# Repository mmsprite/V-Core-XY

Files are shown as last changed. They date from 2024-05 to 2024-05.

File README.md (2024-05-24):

# V-Core-XY
An Open Source upgrade of the Tronxy X5SA Pro to a highly capable 3D Printer based on Klipper and the Voron Teams Designs

**CAUTION: THIS PRINTER IS NOT BEGINNER FRIENDLY TO BUILD, MAKE SURE YOU HAVE EXPERIENCE OR HAVE SOMEONE EXPERIENCED WITH YOU**

Step 1: Choosing your Parts
https://docs.google.com/spreadsheets/d/1tDaB7JIVnb1R4yDRam50uJWcxuR9Q7Ubok1-GsZLodY/edit?usp=sharing

**Required Options:**

**Boards:**
SKR 3 or SKR Mini E3 V3

**Toolhead:**
Voron Stealthburner

**Hotends:**
Any Voron Stealthburner compatible,
recommended: Phaetus Dragon HF

**Extruders:**
Clockwork 2 or Galileo 2 (recommended)

**Optionals:** 
Enclosure,
Klipperscreen Touchscreen,
Camera,
Voron Stealthburner with BTT Knomi,
LED Printarea Lights

**INSTRUCTIONS**
Step 0:
Purchase all required Parts of the BOM and a Tronxy X5SA-Pro(buying a used one is recommended)

Step 1:
3D Print all required Parts and chosen Optional Parts, recommended is PETG or PLA+
Custom Parts of the V-CORE-XY Project are marked with an [a] for to indicate Accent Parts to be printed in a chosen Accent color if desired
the quantity of needed Parts is marked with a (qX)

Step 2:
assemble the Parts as directed by their individual Instructions and Mount them to the Printer

Step 3: Wiring
Wiring can be confusing, i recommend using the Pinouts of the SKR Boards to help, it may require Trial and Error to get the Wiring right

Step 4: Flashing https://docs.mainsail.xyz/
Install Mainsail on the Raspberry Pi and flash the SKR with the Klipper firmware 

Step 5: Done
Enjoy your new Printer with all its upgrades
If needed you can add a Touchscreen and Lights as directed, the Printer is also compatible with any Klipper compatible Project like Enraged Rabbit for Multimaterial Printing

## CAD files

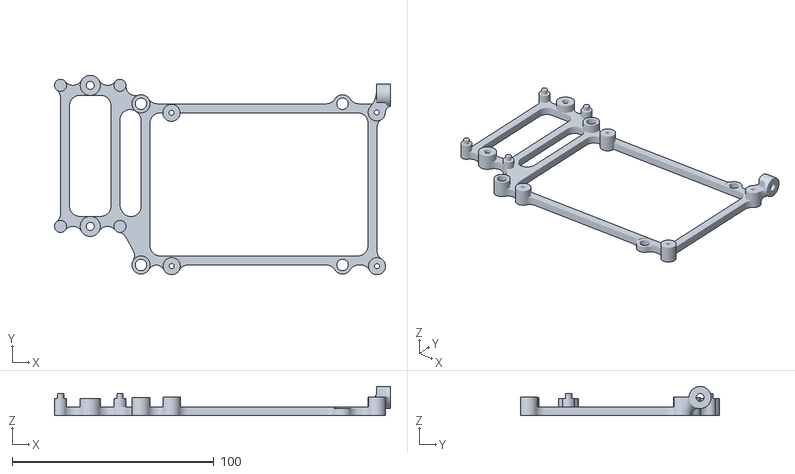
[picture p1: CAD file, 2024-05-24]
Required Printed Parts/SKR 3 Adapter (q1).stl
166.7 x 99.0 x 14.5

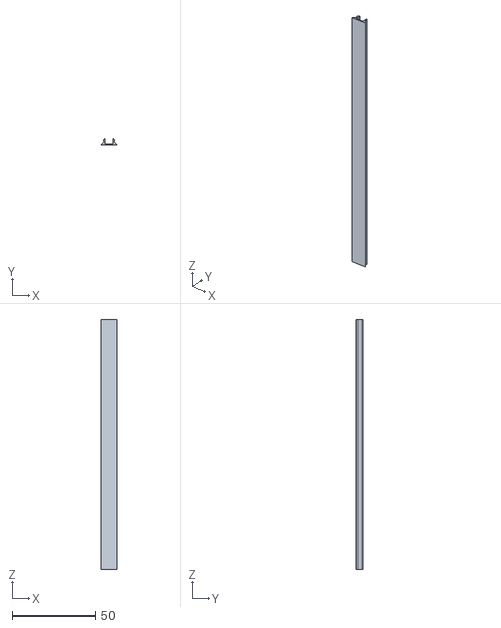
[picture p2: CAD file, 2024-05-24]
Required Printed Parts/vslot cover.stl
9.40 x 4.00 x 150.0

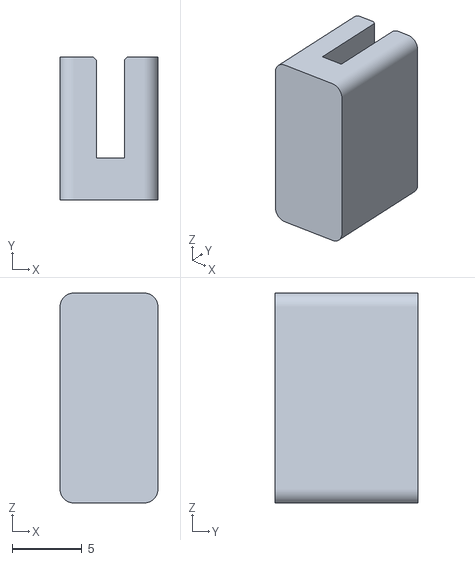
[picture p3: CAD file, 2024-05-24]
Required Printed Parts/GT2 BELT CLAMP (q4).stl
7.00 x 10.2 x 15.0

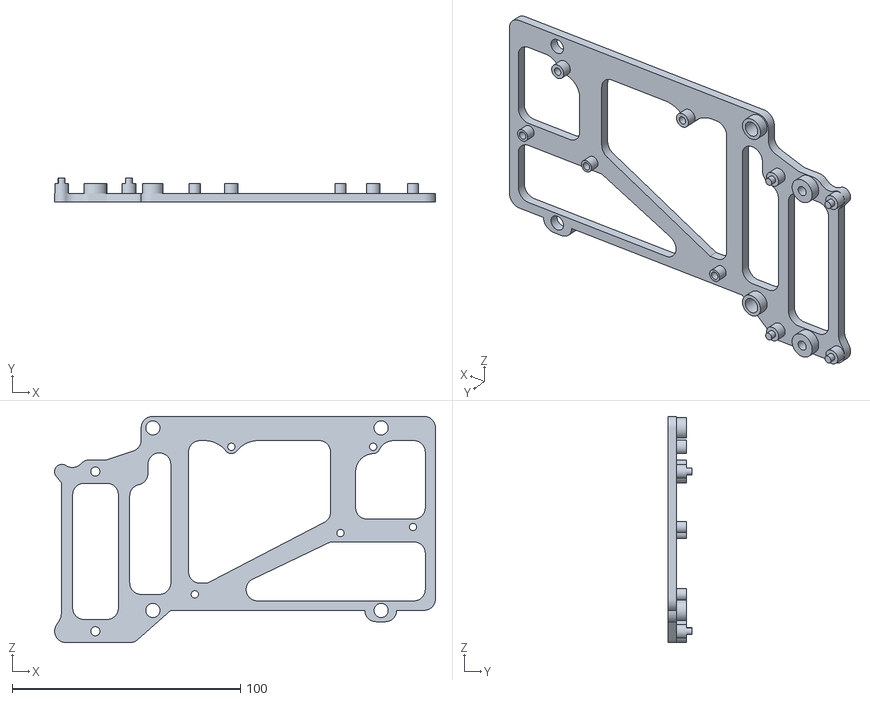
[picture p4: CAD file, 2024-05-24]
Required Printed Parts/SKR MINI E3 V3 Adapter.stl
167.0 x 10.5 x 99.1

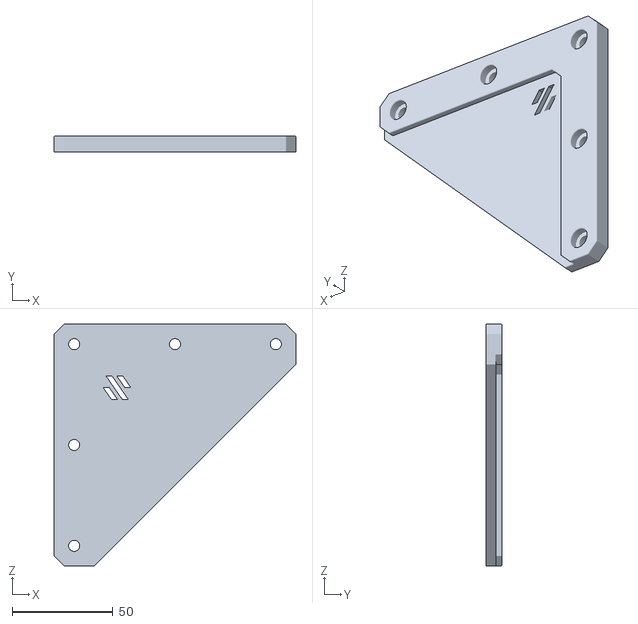
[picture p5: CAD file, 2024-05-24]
Required Printed Parts/CornerBrace(q8).stl
120.0 x 8.00 x 120.0

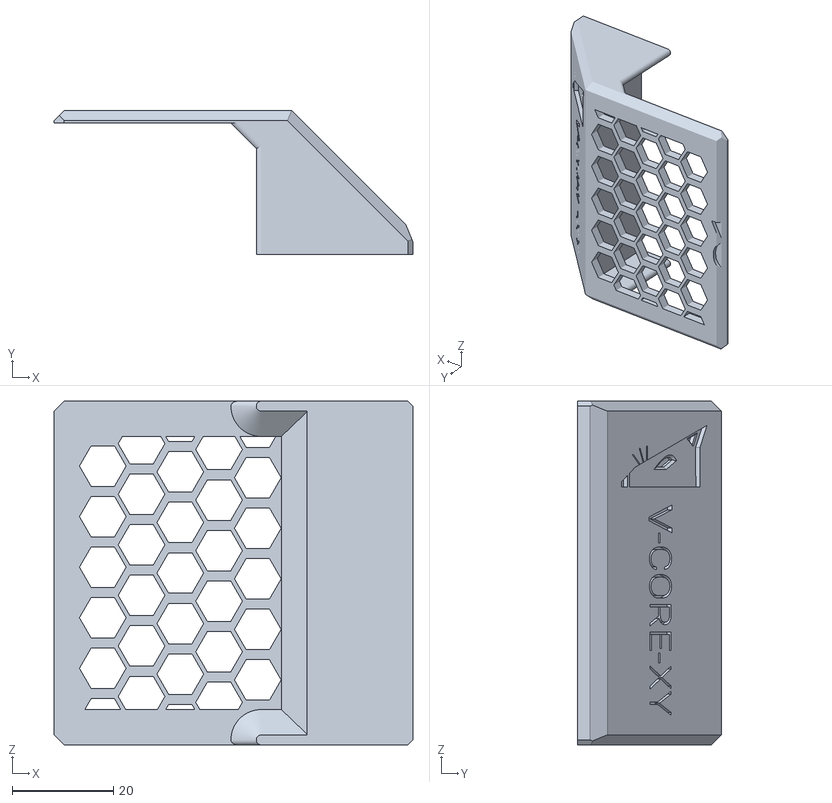
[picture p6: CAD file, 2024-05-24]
Required Printed Parts/Belt Axis Cover (q2).stl
71.0 x 28.5 x 68.0

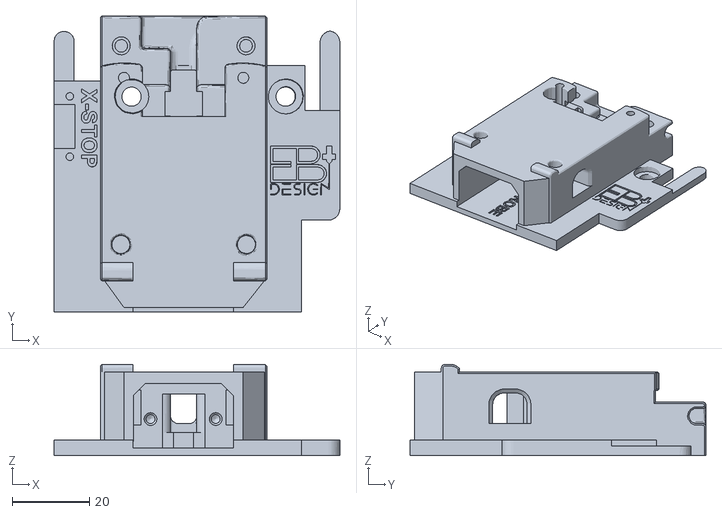
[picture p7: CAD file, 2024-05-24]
Required Printed Parts/Stealthburner Adapter (q1) PETG.stl
74.2 x 76.9 x 23.7

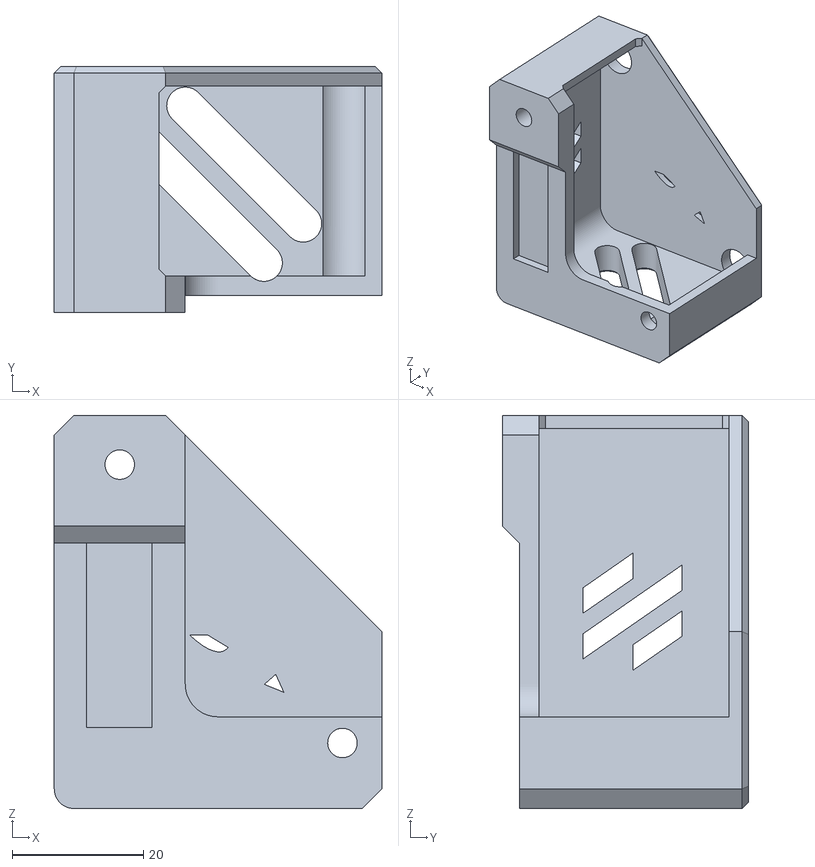
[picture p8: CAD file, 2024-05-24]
Required Printed Parts/Ratrig X Voron Corner Belt Cover [a] (q2).stl
50.0 x 37.6 x 60.0

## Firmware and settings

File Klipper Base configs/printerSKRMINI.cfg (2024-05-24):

[include mainsail.cfg]
[include KAMP_Settings.cfg]
[exclude_object]
[include macros.cfg]
#[include PIS.cfg]
[include led_progress.cfg]

[virtual_sdcard]
path: /home/pi/printer_data/gcodes
on_error_gcode: CANCEL_PRINT

[mcu]
serial: /dev/serial/by-id/usb-Klipper_stm32g0b1xx_1B002C001250415833323520-if00
restart_method: command

[neopixel my_neopixel]
pin: PA8
chain_count: 148
initial_RED: 0.4
initial_GREEN: 0.4
initial_BLUE: 0.4

[gcode_macro POWER_OFF_PRINTER]
gcode:
  {action_call_remote_method(
    "set_device_power", device="V-Core", state="off"
  )}
  
[delayed_gcode delayed_printer_off]
initial_duration: 0.
gcode:
  {% if printer.idle_timeout.state == "Idle" %}
    POWER_OFF_PRINTER
  {% endif %}

[idle_timeout]
gcode:
  M84
  TURN_OFF_HEATERS
  UPDATE_DELAYED_GCODE ID=delayed_printer_off DURATION=6


[printer]
kinematics: corexy
max_velocity: 500
max_accel: 15000
max_z_velocity: 20
max_z_accel: 100

[safe_z_home]
home_xy_position: 165,142 # Change coordinates to the center of your print bed
speed: 120
z_hop: 5                 # Move up 10mm
z_hop_speed: 10

[bed_mesh]
speed: 140
horizontal_move_z: 2.5
mesh_min: 10, 22
mesh_max: 315, 305
probe_count: 6,6

[gcode_macro PROBE_DOWN]
gcode:
    SET_PIN PIN=probe_enable VALUE=1

[gcode_macro PROBE_UP]
gcode:
    SET_PIN PIN=probe_enable VALUE=0

[output_pin probe_enable]
pin: PA1  # Set to the control pin on your board
value: 0

[probe]
pin: ^!PC14  # NOTE FOR V2 users: Set this to ^!PC14 to set the low level trigger 
deactivate_on_each_sample: False
speed: 2.5
x_offset: 0
y_offset: 20
z_offset: 0.76
samples: 1
samples_tolerance: 0.02
samples_tolerance_retries: 3
activate_gcode:
    PROBE_DOWN
    G4 P500
deactivate_gcode:
    PROBE_UP

[stepper_x]
step_pin: PB13
dir_pin: !PB12
enable_pin: !PB14
microsteps: 64
rotation_distance: 40
endstop_pin: !PC0
position_endstop: 0
position_max: 336
homing_speed: 100

[tmc2209 stepper_x]
uart_pin: PC11
tx_pin: PC10
uart_address: 0
run_current: 1.4
stealthchop_threshold: 999999

[stepper_y]
step_pin: PB10
dir_pin: !PB2
enable_pin: !PB11
microsteps: 64
rotation_distance: 40
endstop_pin: !PC1
position_endstop: 0
position_max: 305
homing_speed: 100

[tmc2209 stepper_y]
uart_pin: PC11
tx_pin: PC10
uart_address: 2
run_current: 1.4
stealthchop_threshold: 999999

[stepper_z]
step_pin: PB0
dir_pin: !PC5
enable_pin: !PB1
microsteps: 16
rotation_distance: 8
endstop_pin: probe:z_virtual_endstop
position_max: 380
position_min: -2

[tmc2209 stepper_z]
uart_pin: PC11
tx_pin: PC10
uart_address: 1
run_current: 0.580
hold_current: 0.500
stealthchop_threshold: 999999

[extruder]
step_pin: !PB3
dir_pin: !PB4
enable_pin: !PD1
rotation_distance: 47.088
gear_ratio: 9:1
microsteps: 16
nozzle_diameter: 0.400
filament_diameter: 1.750
heater_pin: PC8
sensor_type: EPCOS 100K B57560G104F
sensor_pin: PA0
#control: pid
#pid_Kp: 21.527
#pid_Ki: 1.063
#pid_Kd: 108.982
min_temp: 0
max_temp: 350
max_extrude_only_distance: 350
max_extrude_cross_section: 5
min_extrude_temp: 20
pressure_advance: 0

[tmc2209 extruder]
uart_pin: PC11
tx_pin: PC10
uart_address: 3
run_current: 0.7
stealthchop_threshold: 0

[firmware_retraction]
retract_length: 2.5
retract_speed: 24
unretract_extra_length: 0
unretract_speed: 30



[heater_bed]
heater_pin: PC9
sensor_type: ATC Semitec 104GT-2
sensor_pin: PC4
#control: pid
#pid_Kp: 54.027
#pid_Ki: 0.770
#pid_Kd: 948.182
min_temp: 0
max_temp: 130

[heater_fan heatbreak_cooling_fan]
pin: PC6

[controller_fan controller_fan]
pin: PC7
stepper: stepper_x

[fan]
pin: PB15

[fan_generic enclosure_fan]
pin: PB5




[screws_tilt_adjust]
screw1:5,275
screw2:320,275
screw3:5,0
screw4:320,0
speed: 150
horizontal_move_z: 5

#[board_pins]
#aliases:
    # EXP1 header
    #EXP1_1=PB5,  EXP1_3=PA9,   EXP1_5=PA10, EXP1_7=PB8, EXP1_9=<GND>,
    #EXP1_2=PA15, EXP1_4=<RST>, EXP1_6=PB9,  EXP1_8=PD6, EXP1_10=<5V>

#*# <---------------------- SAVE_CONFIG ---------------------->
#*# DO NOT EDIT THIS BLOCK OR BELOW. The contents are auto-generated.
#*#
#*# [extruder]
#*# control = pid
#*# pid_kp = 20.230
#*# pid_ki = 0.905
#*# pid_kd = 113.036
#*#
#*# [heater_bed]
#*# control = pid
#*# pid_kp = 70.866
#*# pid_ki = 1.109
#*# pid_kd = 1132.082
#*#
#*# [input_shaper]
#*# shaper_type_x = mzv
#*# shaper_freq_x = 67.8
#*# shaper_type_y = ei
#*# shaper_freq_y = 61.8

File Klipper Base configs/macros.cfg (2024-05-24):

#### MACROS

[gcode_macro NOZZLE_WIPE]
gcode:
    G90
    G1 Z10 F3000
    G1 X335 Y45 Z3.2 F3000
    G1 X335 Y25 F10000 #1
    G1 X335 Y45 F10000
    G1 X335 Y25 F10000 #2
    G1 X335 Y45 F10000
    G1 X335 Y25 F10000 #3
    G1 X335 Y45 F10000
    G1 X335 Y25 F10000 #4
    G1 X335 Y45 F10000
    G1 X335 Y25 F10000 #5
    G1 X335 Y45 F10000
    G1 X335 Y25 F10000 #6
    G1 X335 Y45 F10000
    G1 X335 Y25 F10000 #7
    G1 X335 Y45 F10000
    G1 X335 Y25 F10000 #8
    G1 X335 Y45 F10000
    G1 X335 Y25 F10000 #9
    G1 X335 Y45 F10000
    G1 X335 Y25 F10000 #10
    G1 Z10 F3000
    G1 X165 Y165 F3000
   
    

[gcode_macro START_PRINT]
gcode:
    {% set BED_TEMP = params.BED_TEMP|default(65)|float %}
    {% set EXTRUDER_TEMP = params.EXTRUDER_TEMP|default(215)|float %}
    G28
    G90
    G1 X0 Y305 Z15 F4000
    NEOPIXEL_DISPLAY LED=my_neopixel TYPE=bed_temp MODE=glow
    M190 S{BED_TEMP}
    BED_MESH_CALIBRATE
    G90
    SMART_PARK
    NEOPIXEL_DISPLAY LED=my_neopixel TYPE=extruder_temp MODE=glow
    M109 S{EXTRUDER_TEMP}
    VORON_PURGE
    NEOPIXEL_DISPLAY LED=my_neopixel TYPE=print_percent MODE=glow

[gcode_macro END_PRINT]
gcode:
    # Turn off bed, extruder, and fan
    M140 S0
    M104 S0
    M106 S0
    # Move nozzle away from print while retracting
    G91
    G1 E-5 F2700 ;Retract a bit
    # Raise nozzle by 10mm
    # Move Bed all the way down and Move Toolhead to Home
    G91
    G1 Z20 F3000
    G90 
    G1 X20 Y305  F5000
    M84
    SET_LED LED=my_neopixel RED=0 GREEN=0.3 BLUE=0.3 INDEX=145



[gcode_macro PAUSE]
description: Pause the actual running print
rename_existing: PAUSE_BASE
gcode:
  PAUSE_BASE
  _TOOLHEAD_PARK_PAUSE_CANCEL

#M205 is added by Cura and not supported by Klipper
[gcode_macro M205]
gcode: M117 Printing...

[gcode_macro M600]
gcode:
  {% set X = params.X|default(50)|float %}
  {% set Y = params.Y|default(0)|float %}
  {% set Z = params.Z|default(10)|float %}
  SAVE_GCODE_STATE NAME=M600_state
  PAUSE
  G91
    G1 E-3 F2700 ;Retract a bit
    # Raise nozzle by 10mm
    # Move Bed all the way down and Move Toolhead to Home
    G91
    G1 Z20 F3000
    G90 
    G1 X0 Y305  F3000
  G91
  #G1 E-150 F500 retract
  RESTORE_GCODE_STATE NAME=M600_state
  #SET_IDLE_TIMEOUT TIMEOUT=43000

[gcode_macro G29]
gcode: 
  G28
  BED_MESH_CALIBRATE
  BED_MESH_PROFILE SAVE=probed
  BED_MESH_PROFILE LOAD=probed

[gcode_macro CANCEL_PRINT]
description: Cancel the actual running print
rename_existing: CANCEL_PRINT_BASE
gcode:
  # Turn off bed, extruder, and fan
    M140 S0
    M104 S0
    M106 S0
    # Move nozzle away from print while retracting
    G91
    G1 E-3 F2700 ;Retract a bit
    # Raise nozzle by 10mm
    # Move Bed all the way down and Move Toolhead to Home
    G91
    G1 Z20 F3000
    G90 
    G1 X0 Y305  F3000
    M84
  CLEAR_PAUSE
  SDCARD_RESET_FILE

[gcode_macro M600]
description: Starts process of Filament Change
gcode:
  {% if printer.extruder.temperature < 180 %}
    {action_respond_info("Extruder temperature too low")}
  {% else %}
    PAUSE_MACRO
    _DISABLE_FS
    UNLOAD_FILAMENT
  {% endif %}
 
[gcode_macro PAUSE_MACRO]
description: Pauses Print
gcode:
    PAUSE
    SET_IDLE_TIMEOUT TIMEOUT={ 30 * 60 }
 
[gcode_macro FC_RESUME]
description: Resume print after Filament Change
gcode:
    ##### read E from pause macro #####
    {% set E = printer["gcode_macro PAUSE"].extrude|float %}
    SET_IDLE_TIMEOUT TIMEOUT={ 10 * 60 }
    G1 E-{ E }
    # Reset extruder position
    G92 E0
    RESUME
 
[gcode_macro UNLOAD_FILAMENT]
description: Unloads Filament from extruder
gcode:
  {% if printer.extruder.temperature < 180 %}
    {action_respond_info("Extruder temperature too low")}
  {% else %}
    SAVE_GCODE_STATE NAME=UNLOAD_state
    {% set Z = params.Z|default(50)|int %}
    {% set axis_max = printer.toolhead.axis_maximum %}
    {% set pos = printer.toolhead.position %}
 
    {% set z_diff = axis_max.z - pos.z %}
    {% set z_safe_lift = [ Z, z_diff ] | min%}
 
    G91                   # relative positioning
    G0 Z{ z_safe_lift }
    # Reset extruder position
    G92 E0
    G1 E5.0 F300        # extrude a little
    G1 E-50 F{ 10 * 60 } # perform the unload
    G1 E-50 F{ 5 * 60 }   # finish the unload
    RESTORE_GCODE_STATE NAME=UNLOAD_state
  {% endif %}
 
[gcode_macro PURGE]
description: Extrudes filament, used to clean out previous filament
gcode:
  {% if printer.extruder.temperature < 180 %}
    {action_respond_info("Extruder temperature too low")}
  {% else %}
  {% set PURGE_AMOUNT = params.PURGE_AMOUNT|default(40)|float %}
    SAVE_GCODE_STATE NAME=PURGE_state
    G91                   # relative coords
    G1 E{PURGE_AMOUNT} F{ 5 * 60 }  # purge
    RESTORE_GCODE_STATE NAME=PURGE_state
  {% endif %}
 
[gcode_macro LOAD_FILAMENT]
description: Loads filament into the extruder
gcode:
  {% if printer.extruder.temperature < 180 %}
    {action_respond_info("Extruder temperature too low")}
  {% else %}
    SAVE_GCODE_STATE NAME=LOAD_state
    G91                   # Relative coords
    G1 E50 F{ 5 * 60 }  # extrude
    G4 P{ 0.9 * 1000 }    # dwell (ms)
    G1 E25.0 F{ 5 * 60 }  # extrude a little more
    _ENABLE_FS
    RESTORE_GCODE_STATE NAME=LOAD_state
  {% endif %}
 
[gcode_macro _DISABLE_FS]
description: placeholder, disables filament sensor that might trigger an M600 in the middle of a load/unload/M600...
gcode:
    SET_FILAMENT_SENSOR SENSOR=RunoutSensor ENABLE=0
 
[gcode_macro _ENABLE_FS]
description: placeholder, enables filament sensor
gcode:
    SET_FILAMENT_SENSOR SENSOR=RunoutSensor ENABLE=1
 
[gcode_macro HEAT]
description: Heats up the extruder to get ready for Filament Change
gcode:
  {% set EXTRUDER_TEMP = params.EXTRUDER_TEMP|default(200)|float %}
  {% set Z = params.Z|default(50)|float %}
  {% set X = params.X|default(110)|float %}
  {% set Y = params.Y|default(110)|float %}
  SET_HEATER_TEMPERATURE HEATER=extruder TARGET={EXTRUDER_TEMP}
  HOME_CHECK
  G1 Z{Z} F500
  G1 X{X} Y{Y} F6000
 
[gcode_macro COOL]
description: Turns off all heaters
gcode:
  TURN_OFF_HEATERS
 

 
[gcode_macro BED_TRAMMING_1]
description: Heats bed and starts process to level the bed with the screws
gcode:
  {% set BED_TEMP = params.BED_TEMP|default(60)|float %} 
  SET_HEATER_TEMPERATURE HEATER=heater_bed TARGET={BED_TEMP}
  HOME_CHECK
  M190 S{BED_TEMP}
  SCREWS_TILT_CALCULATE
 
[gcode_macro BED_TRAMMING_2]
description: Continues the bed screw leveling process
gcode:
  SCREWS_TILT_CALCULATE
 
[gcode_macro BED_MESH]
description: Heats bed, makes a mesh and saves it
gcode:
  {% set BED_TEMP = params.BED_TEMP|default(60)|float %} 
  SET_HEATER_TEMPERATURE HEATER=heater_bed TARGET={BED_TEMP}
  HOME_CHECK
  M190 S{BED_TEMP}
  BED_MESH_CLEAR
  BED_MESH_CALIBRATE
  TURN_OFF_HEATERS
  SAVE_CONFIG
 
[gcode_macro DISABLE_STEPPERS]
description: Disables the printers stepper motors
gcode:
  M84 X Y E
 
[gcode_macro PID_EXTRUDER]
description: PID Tune for the Extruder
gcode:
  {% set TARGET_TEMP = params.TARGET_TEMP|default(200)|float %} 
  PID_CALIBRATE HEATER=extruder TARGET={TARGET_TEMP}
  TURN_OFF_HEATERS
  SAVE_CONFIG
 
[gcode_macro PID_BED]
description: PID Tune for the Bed
gcode:
  {% set TARGET_TEMP = params.TARGET_TEMP|default(60)|float %} 
  PID_CALIBRATE HEATER=heater_bed TARGET={TARGET_TEMP}
  TURN_OFF_HEATERS
  SAVE_CONFIG
 
[gcode_macro NOZZLE_MID]
description: Moves nozzle to the center of the bed
gcode:
  {% set Z = params.Z|default(10)|float %}
  HOME_CHECK
  G1 Z{Z} F500
  G1 X110 Y110 F6000
 
[gcode_macro home_check]
description: Checks if the printer is homed, it not it homes the printer
gcode:
  {% if printer.toolhead.homed_axes != "xyz" %}
  G28
  {% endif %}
 
[gcode_macro SHOW_PRINT]
description: Moves the extruder out of the way and bed forward
gcode:
    HOME_CHECK
    {% set Z = params.Z|default(50)|int %}
    {% set axis_max = printer.toolhead.axis_maximum %}
    {% set pos = printer.toolhead.position %}
 
    {% set z_diff = axis_max.z - pos.z %}
    {% set z_safe_lift = [ Z, z_diff ] | min%}
    G1 Z{ z_safe_lift }
    G1 X10 Y220 F4000
 
[gcode_macro ZOffset_Setup]
description: Starts Z-Offset Calibration, under 30 degrees Celsius
gcode:
  {% if printer.heater_bed.temperature > 30 %}
    {action_respond_info("Bed temperature too high")}
  {% elif printer.extruder.temperature > 30 %}
    {action_respond_info("Extruder temperature too High")}
  {% else %}
  G28
  PROBE_CALIBRATE
  {% endif %}
 
[gcode_macro Z_Down_01]
description: Moves Z down by 0.1
gcode:
  TESTZ Z=-.1
 
[gcode_macro Z_Up_01]
description: Moves Z up by 0.1
gcode:
  TESTZ Z=+.1
 
[gcode_macro Z_Low_Half]
description: Sets Z between current value and previous lower value
gcode:
  TESTZ Z=-
 
[gcode_macro Z_High_Half]
description: Sets Z between current value and previous higher value
gcode:
  TESTZ Z=+
 
[gcode_macro Accept_Save]
description: Accepts the Z-Offset and saves the config
gcode:
  ACCEPT
  SAVE_CONFIG
 
[gcode_macro Abort_Setup]
description: Aborts the Z-Offset calibration
gcode:
  ABORT
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
